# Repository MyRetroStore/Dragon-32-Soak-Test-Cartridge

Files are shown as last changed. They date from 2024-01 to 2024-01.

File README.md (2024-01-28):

# Dragon 32 Soak Test Cartridge

From the description on [WorldOfDragon](https://archive.worldofdragon.org/index.php?title=Dragon_32_Soak_Test)

_A cartridge designed to test the Dragon 32 hardware in a loop.
The ROM program will change a pattern on screen and lit a green led on the cartridge if tests are passing, and freeze the machine and lit a red led if any test fails.
The cartridge will not work on a Dragon 64 or a Dragon 200 as it performs a ROM checksum and later models will make the checksum test fail._

There is not much documentation on the Soak Test Cartridge for the Dragon 32 computer. 

After finding a photo of the PCB on WorldOfDragon I decided to reverse engineer the PCB 
and with the help of the community on the forums as well as a Dragon 32 Facebook group, I've managed to re-create the schematic and a replica PCB.

## Folders
Hardware - Schematic, PCB layout and Gerbers created with [KiCad](https://www.kicad.org/) 7.0.10

ROM - Binary file from worldofdragon.org

Photos - Photos of the orignal and replica PCB as well as screenshots of the cartridge in action. 

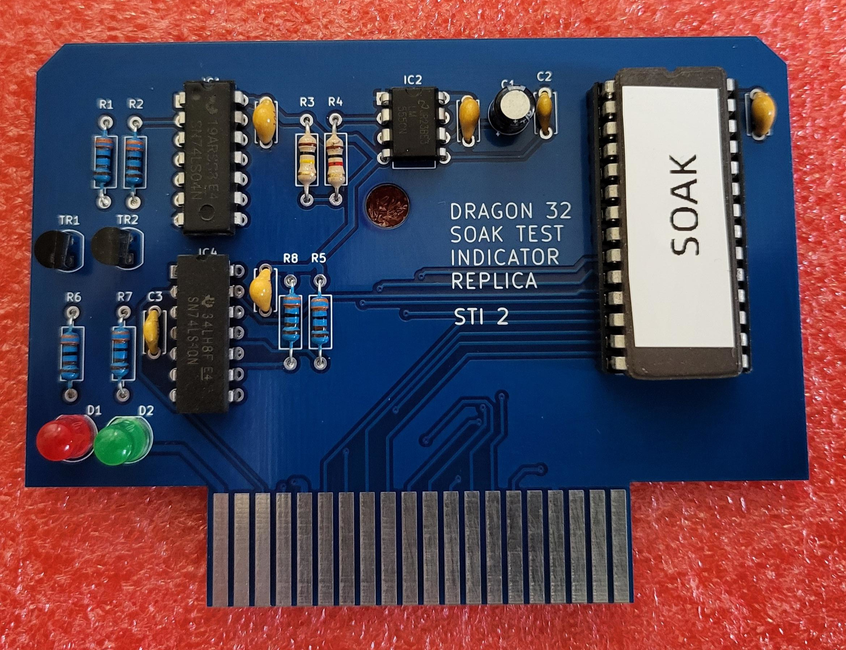
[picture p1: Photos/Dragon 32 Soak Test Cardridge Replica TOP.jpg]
PCB


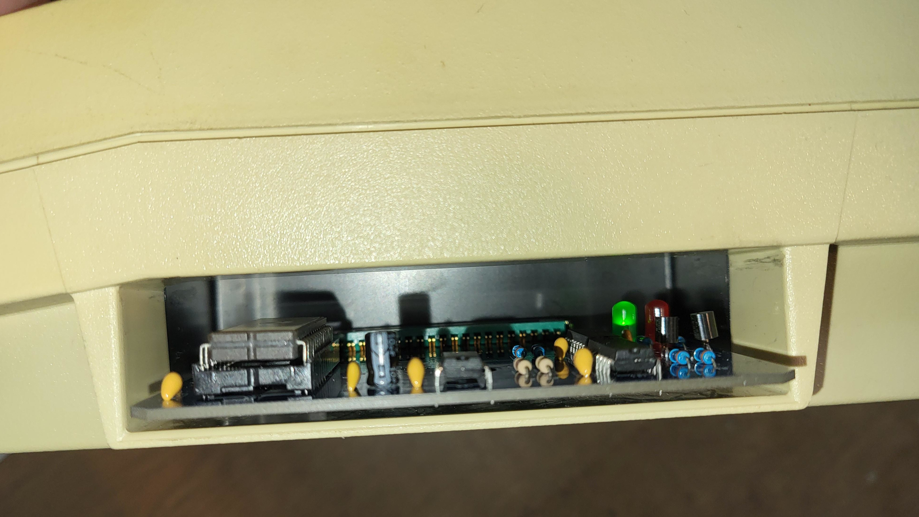
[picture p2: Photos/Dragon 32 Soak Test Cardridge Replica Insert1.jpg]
Inserted


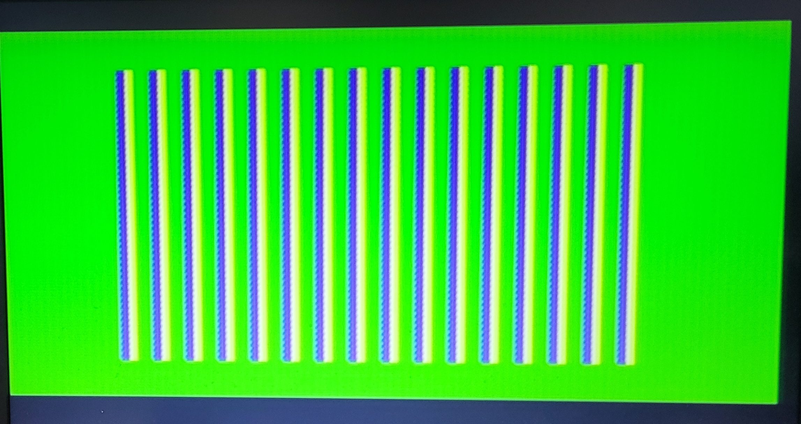
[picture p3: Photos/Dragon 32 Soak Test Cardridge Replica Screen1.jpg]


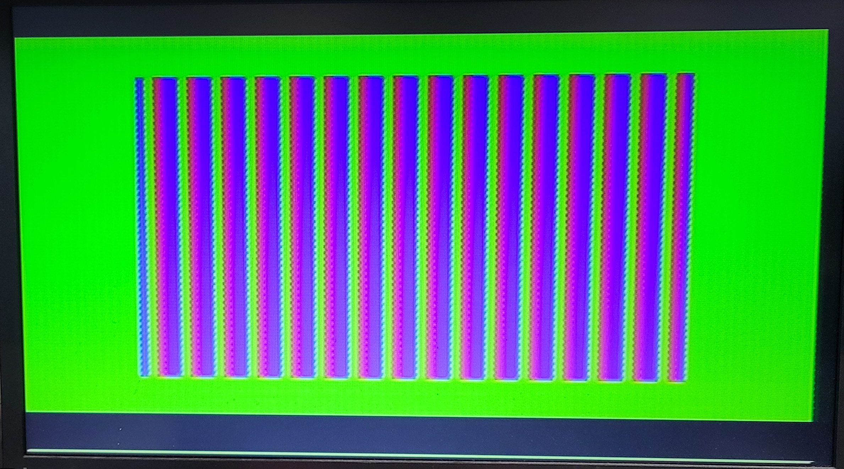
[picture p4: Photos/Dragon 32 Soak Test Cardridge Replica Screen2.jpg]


## BOM

| Reference  | Component |
| --- | --- |
| C1	 | 10u Electrolytic Capacitor |
| C2,C3 | 10n Ceramic Capacitor |
| D1	 | Red 5mm LED |
| D2	 | Green 5mm LED |
| DC1-4	 | 100n Ceramic Capacitor (Decoupling) |
| IC1	 | 74LS04 |
| IC2	 | LM555 |
| IC3	 | EPROM 27C64 |
| IC4	 | 74LS10 |
| R1-2, R5-8 | 3k3 Resistor 0.25W |
| R3 | 100k Resistor 0.25W |
| R4	 | 1k Resistor 0.25W |
| TR1,TR2 | BC237 Transistor |

I've tested the PCB in my Dragon 32 and it seems to work as expected, however I do not take any responsibility if you are building this and there is damage done to your Dragon 32 due to incorrect assembly or it doesn't work as expected. 

While this should be as close as possible a 100% replica to the orignal PCB there could be some error (Though hopefully not. Let me know if you find any) 

## Purchasing

If you don't want build this yourself the completed PCB can be purchased from:
- [MyRetroStore](https://myretrostore.co.uk/)
- [eBay](https://www.ebay.co.uk/str/myretrostoreuk)

## License
GNU General Public License v3.0



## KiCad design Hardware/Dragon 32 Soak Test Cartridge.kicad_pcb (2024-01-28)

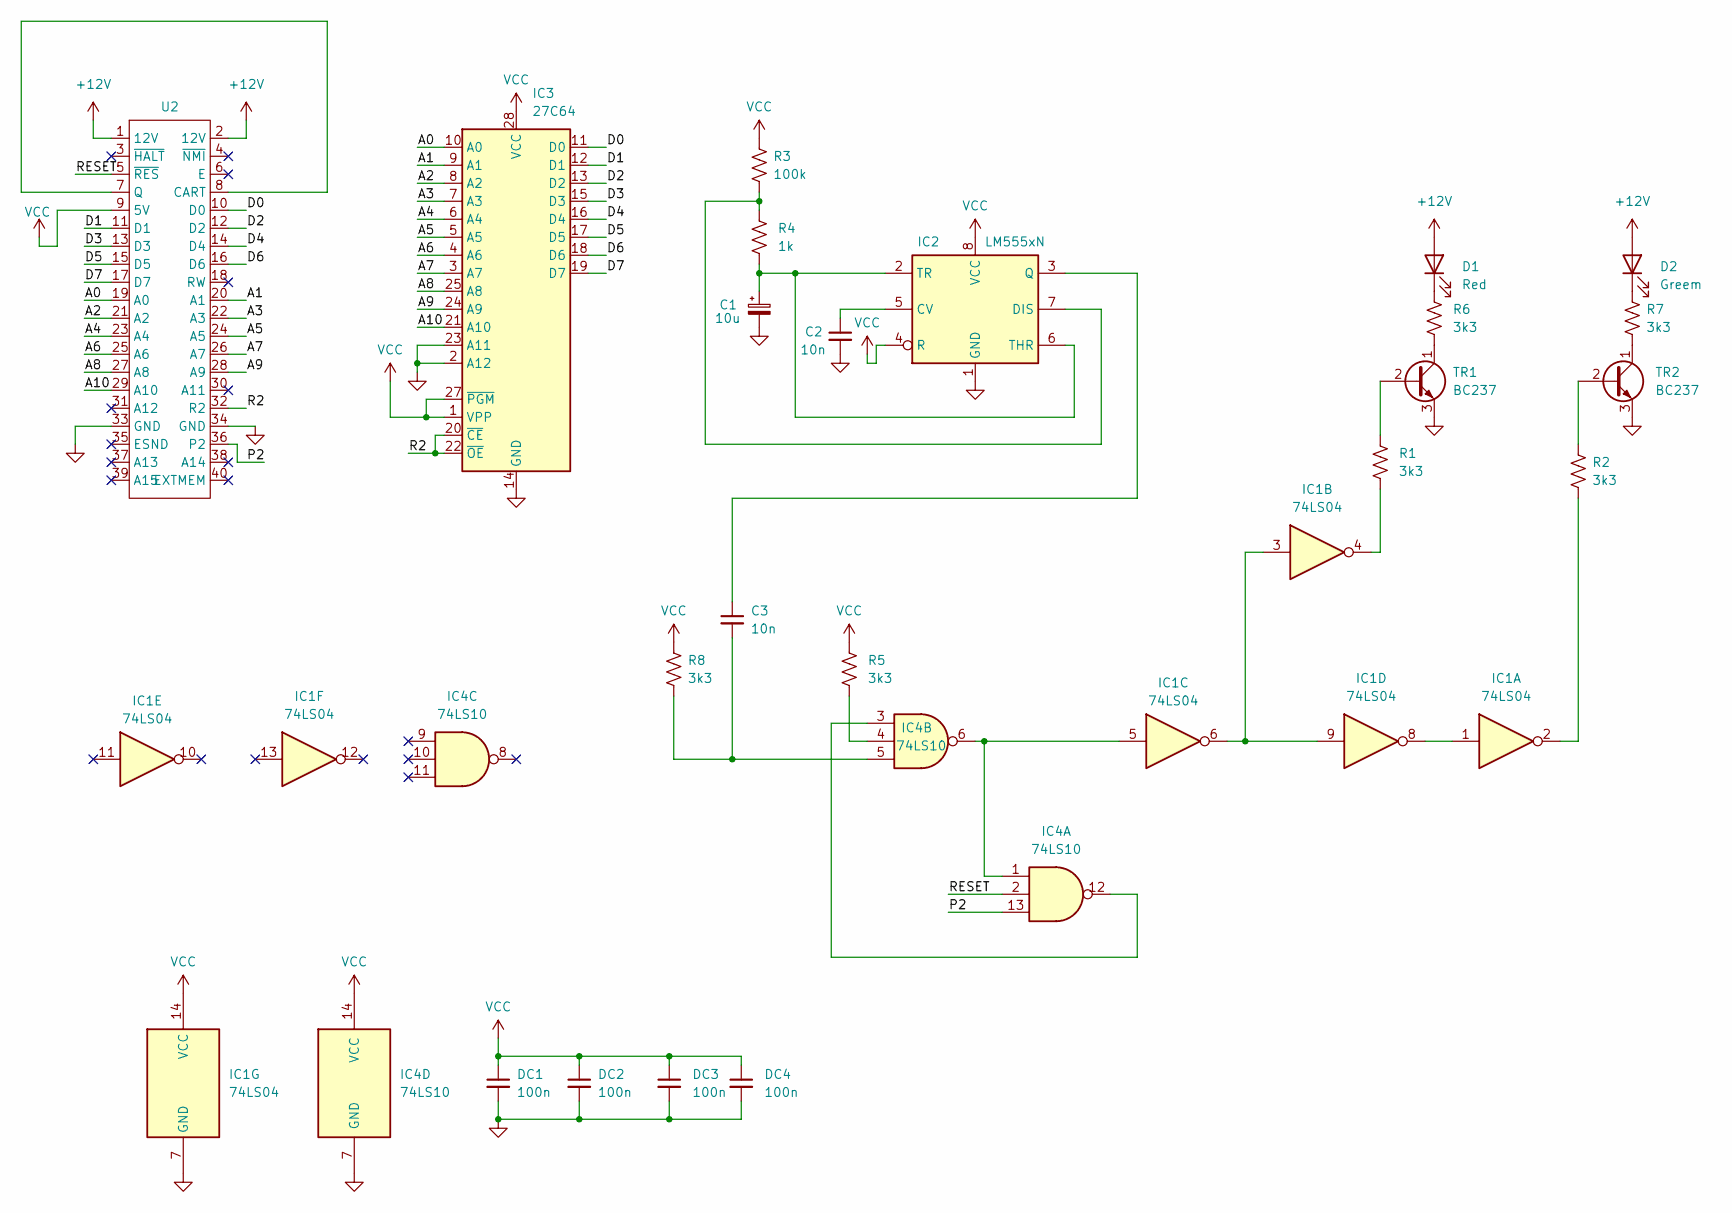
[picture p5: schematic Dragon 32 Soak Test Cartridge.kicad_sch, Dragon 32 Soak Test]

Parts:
C1: 10u; CP_Radial_D5.0mm_P2.50mm
C2, C3: 10n; C_Disc_D5.0mm_W2.5mm_P5.00mm
D1: Red; LED_D5.0mm
D2: Greem; LED_D5.0mm
DC1, DC2, DC3, DC4: 100n; C_Disc_D5.0mm_W2.5mm_P5.00mm
IC1: 74LS04; DIP-14_W7.62mm
IC2: LM555xN; DIP-8_W7.62mm
IC3: 27C64; DIP-28_W15.24mm
IC4: 74LS10; DIP-14_W7.62mm
R1, R2, R5, R6, R7, R8: 3k3; R_Axial_DIN0207_L6.3mm_D2.5mm_P10.16mm_Horizontal
R3: 100k; R_Axial_DIN0207_L6.3mm_D2.5mm_P10.16mm_Horizontal
R4: 1k; R_Axial_DIN0207_L6.3mm_D2.5mm_P10.16mm_Horizontal
TR1, TR2: BC237; TO-92
U2: Dragon 32

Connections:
+12V: D1.2 (A), D2.2 (A), U2.1 (12V), U2.2 (12V)
/A0: IC3.10 (A0), U2.19 (A0)
/A1: IC3.9 (A1), U2.20 (A1)
/A2: IC3.8 (A2), U2.21 (A2)
/A3: IC3.7 (A3), U2.22 (A3)
/A4: IC3.6 (A4), U2.23 (A4)
/A5: IC3.5 (A5), U2.24 (A5)
/A6: IC3.4 (A6), U2.25 (A6)
/A7: IC3.3 (A7), U2.26 (A7)
/A8: IC3.25 (A8), U2.27 (A8)
/A9: IC3.24 (A9), U2.28 (A9)
/A10: IC3.21 (A10), U2.29 (A10)
/D0: IC3.11 (D0), U2.10 (D0)
/D1: IC3.12 (D1), U2.11 (D1)
/D2: IC3.13 (D2), U2.12 (D2)
/D3: IC3.15 (D3), U2.13 (D3)
/D4: IC3.16 (D4), U2.14 (D4)
/D5: IC3.17 (D5), U2.15 (D5)
/D6: IC3.18 (D6), U2.16 (D6)
/D7: IC3.19 (D7), U2.17 (D7)
/P2: IC4.13, U2.36 (P2)
/R2: IC3.20 (~CE), IC3.22 (~OE), U2.32 (R2)
/RESET: IC4.2, U2.5 (~RES)
GND: C1.2, C2.2, DC1.2, DC2.2, DC3.2, DC4.2, IC1.7 (GND), IC2.1 (GND), IC3.2 (A12), IC3.14 (GND), IC3.23 (A11), IC4.7 (GND), TR1.3 (E), TR2.3 (E), U2.33 (GND), U2.34 (GND)
unnamed: C3.2, IC4.5, R8.1
unnamed: D1.1 (K), R6.1
unnamed: D2.1 (K), R7.1
unnamed: IC1.1, IC1.8
unnamed: IC1.2, R2.2
unnamed: IC1.3, IC1.6, IC1.9
unnamed: IC1.4, R1.2
unnamed: IC1.5, IC4.1, IC4.6
unnamed: C2.1, IC2.5 (CV)
unnamed: IC2.7 (DIS), R3.1, R4.1
unnamed: C3.1, IC2.3 (Q)
unnamed: C1.1, IC2.2 (TR), IC2.6 (THR), R4.2
unnamed: IC4.4, R5.2
unnamed: IC4.3, IC4.12
unnamed: R1.1, TR1.2 (B)
unnamed: R6.2, TR1.1 (C)
unnamed: R2.1, TR2.2 (B)
unnamed: R7.2, TR2.1 (C)
unnamed: U2.7 (Q), U2.8 (CART)
VCC: DC1.1, DC2.1, DC3.1, DC4.1, IC1.14 (VCC), IC2.4 (R), IC2.8 (VCC), IC3.1 (VPP), IC3.27 (~PGM), IC3.28 (VCC), IC4.14 (VCC), R3.2, R5.1, R8.2, U2.9 (5V)

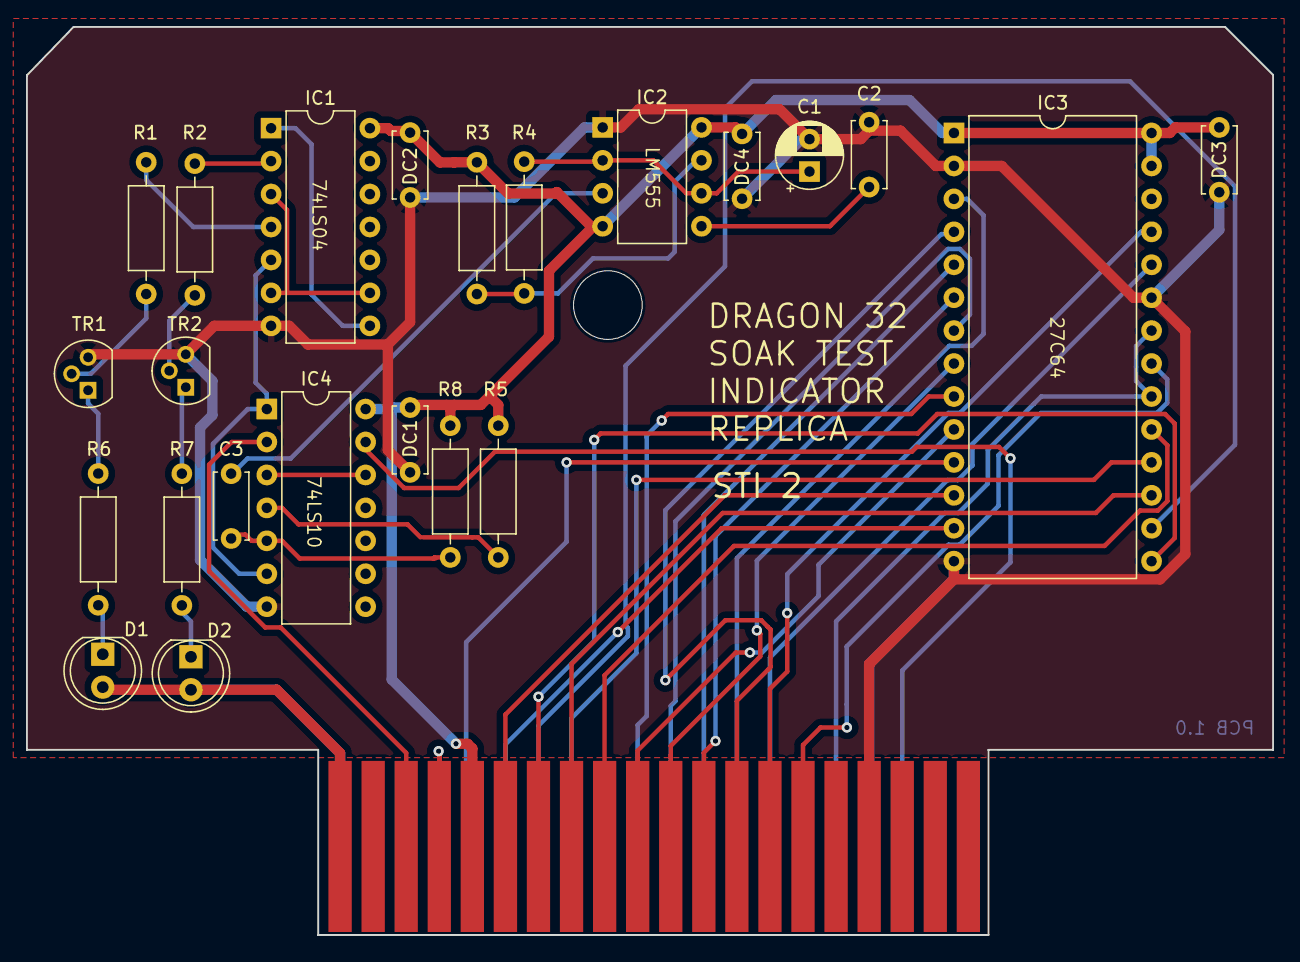
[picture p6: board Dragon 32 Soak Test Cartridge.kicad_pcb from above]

Board: 2 copper layers, 96.1 x 70.0 mm, 24 parts (0 on the bottom side), 44 nets.

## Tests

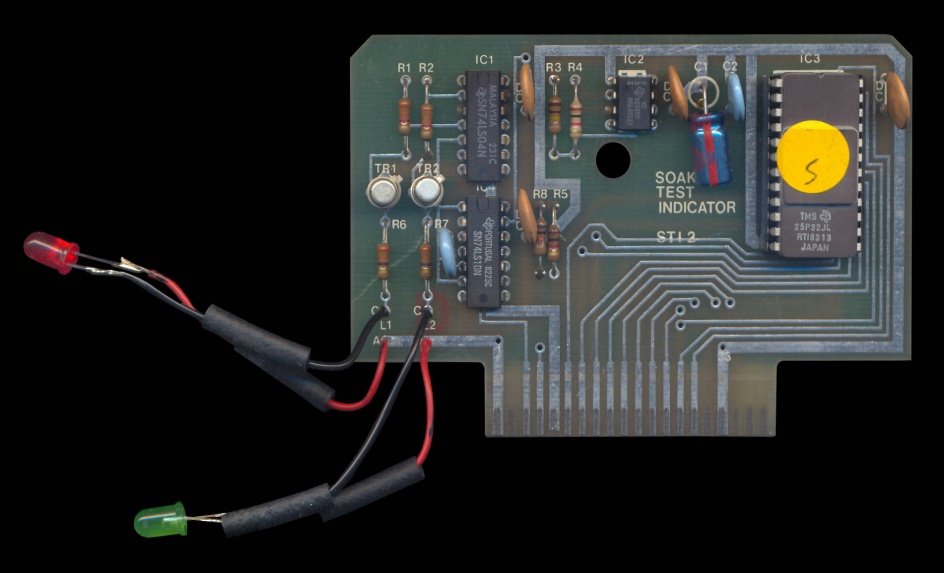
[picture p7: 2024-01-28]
Photos/Dragon32_SoakTest_PCB_Top.jpg

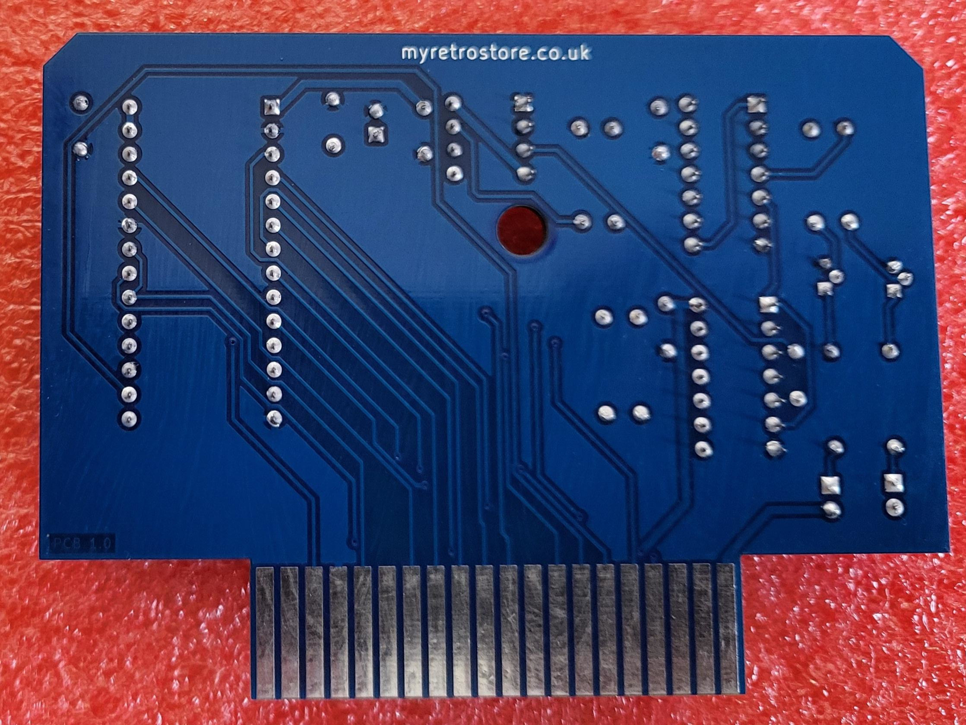
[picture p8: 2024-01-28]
Photos/Dragon 32 Soak Test Cardridge Replica BOTTOM.jpg

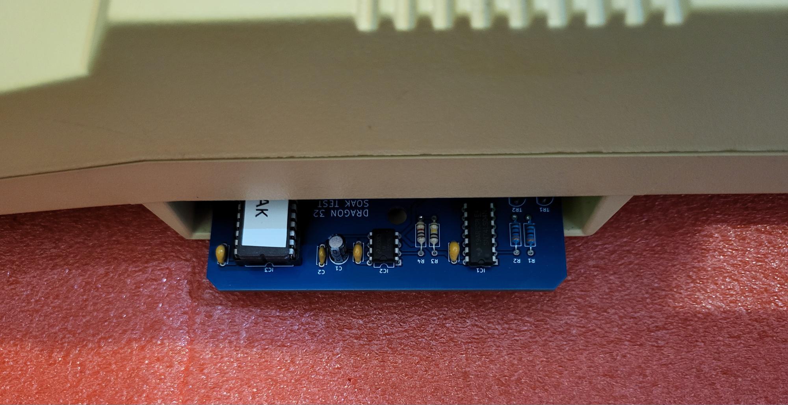
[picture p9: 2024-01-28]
Photos/Dragon 32 Soak Test Cardridge Replica Insert2.jpg

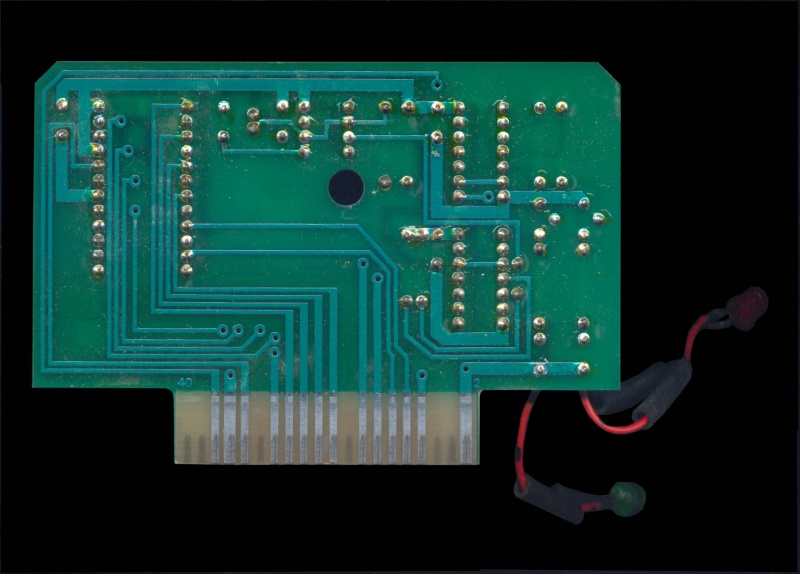
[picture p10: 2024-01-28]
Photos/Dragon32_SoakTest_PCB_Bottom.jpg

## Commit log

2024-01-28 Added BOM
2024-01-28 Updated BOM layout
